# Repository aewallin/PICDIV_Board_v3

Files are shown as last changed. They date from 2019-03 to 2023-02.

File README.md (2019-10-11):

# PICDIV_Board_v3
Programmable 10 MHz to 1PPS frequency divider-board.

The input frequency (sine or square-wave) is first converted to a square-wave and then used as the clock source for a PIC12F675 programmed with the PICDIV firmware (https://github.com/aewallin/PICDIV). Two IDT 5PB1108 buffered outputs are provided. Trimmer-capacitors can be used to accurately tune channel-skew. An LED driven by a timer LTC6993 provides indication of 1PPS signal. A Sync input allows synchronizing the output-1PPS to an input-1PPS, within 100ns (with a 10 MHz clock).

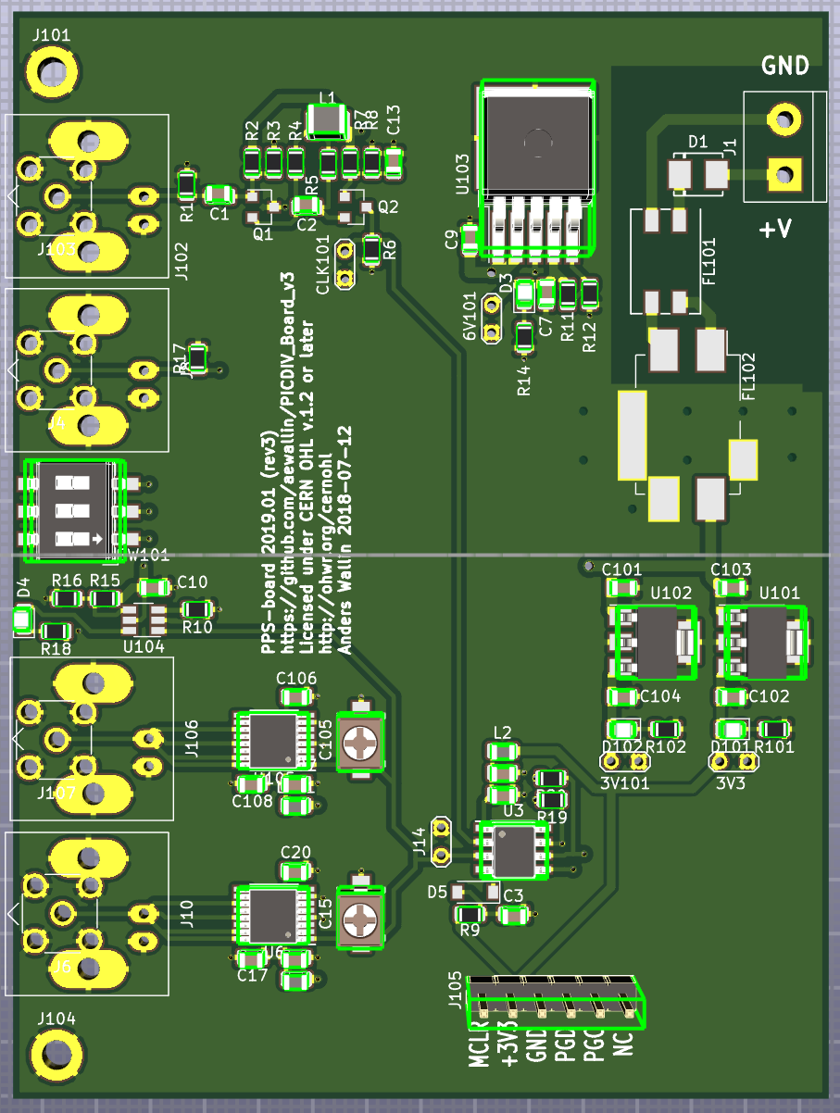
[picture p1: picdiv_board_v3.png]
PCB image


## Firmware

- assembler & build-instructions: https://github.com/aewallin/PICDIV
- original source: http://www.leapsecond.com/pic/picdiv.htm

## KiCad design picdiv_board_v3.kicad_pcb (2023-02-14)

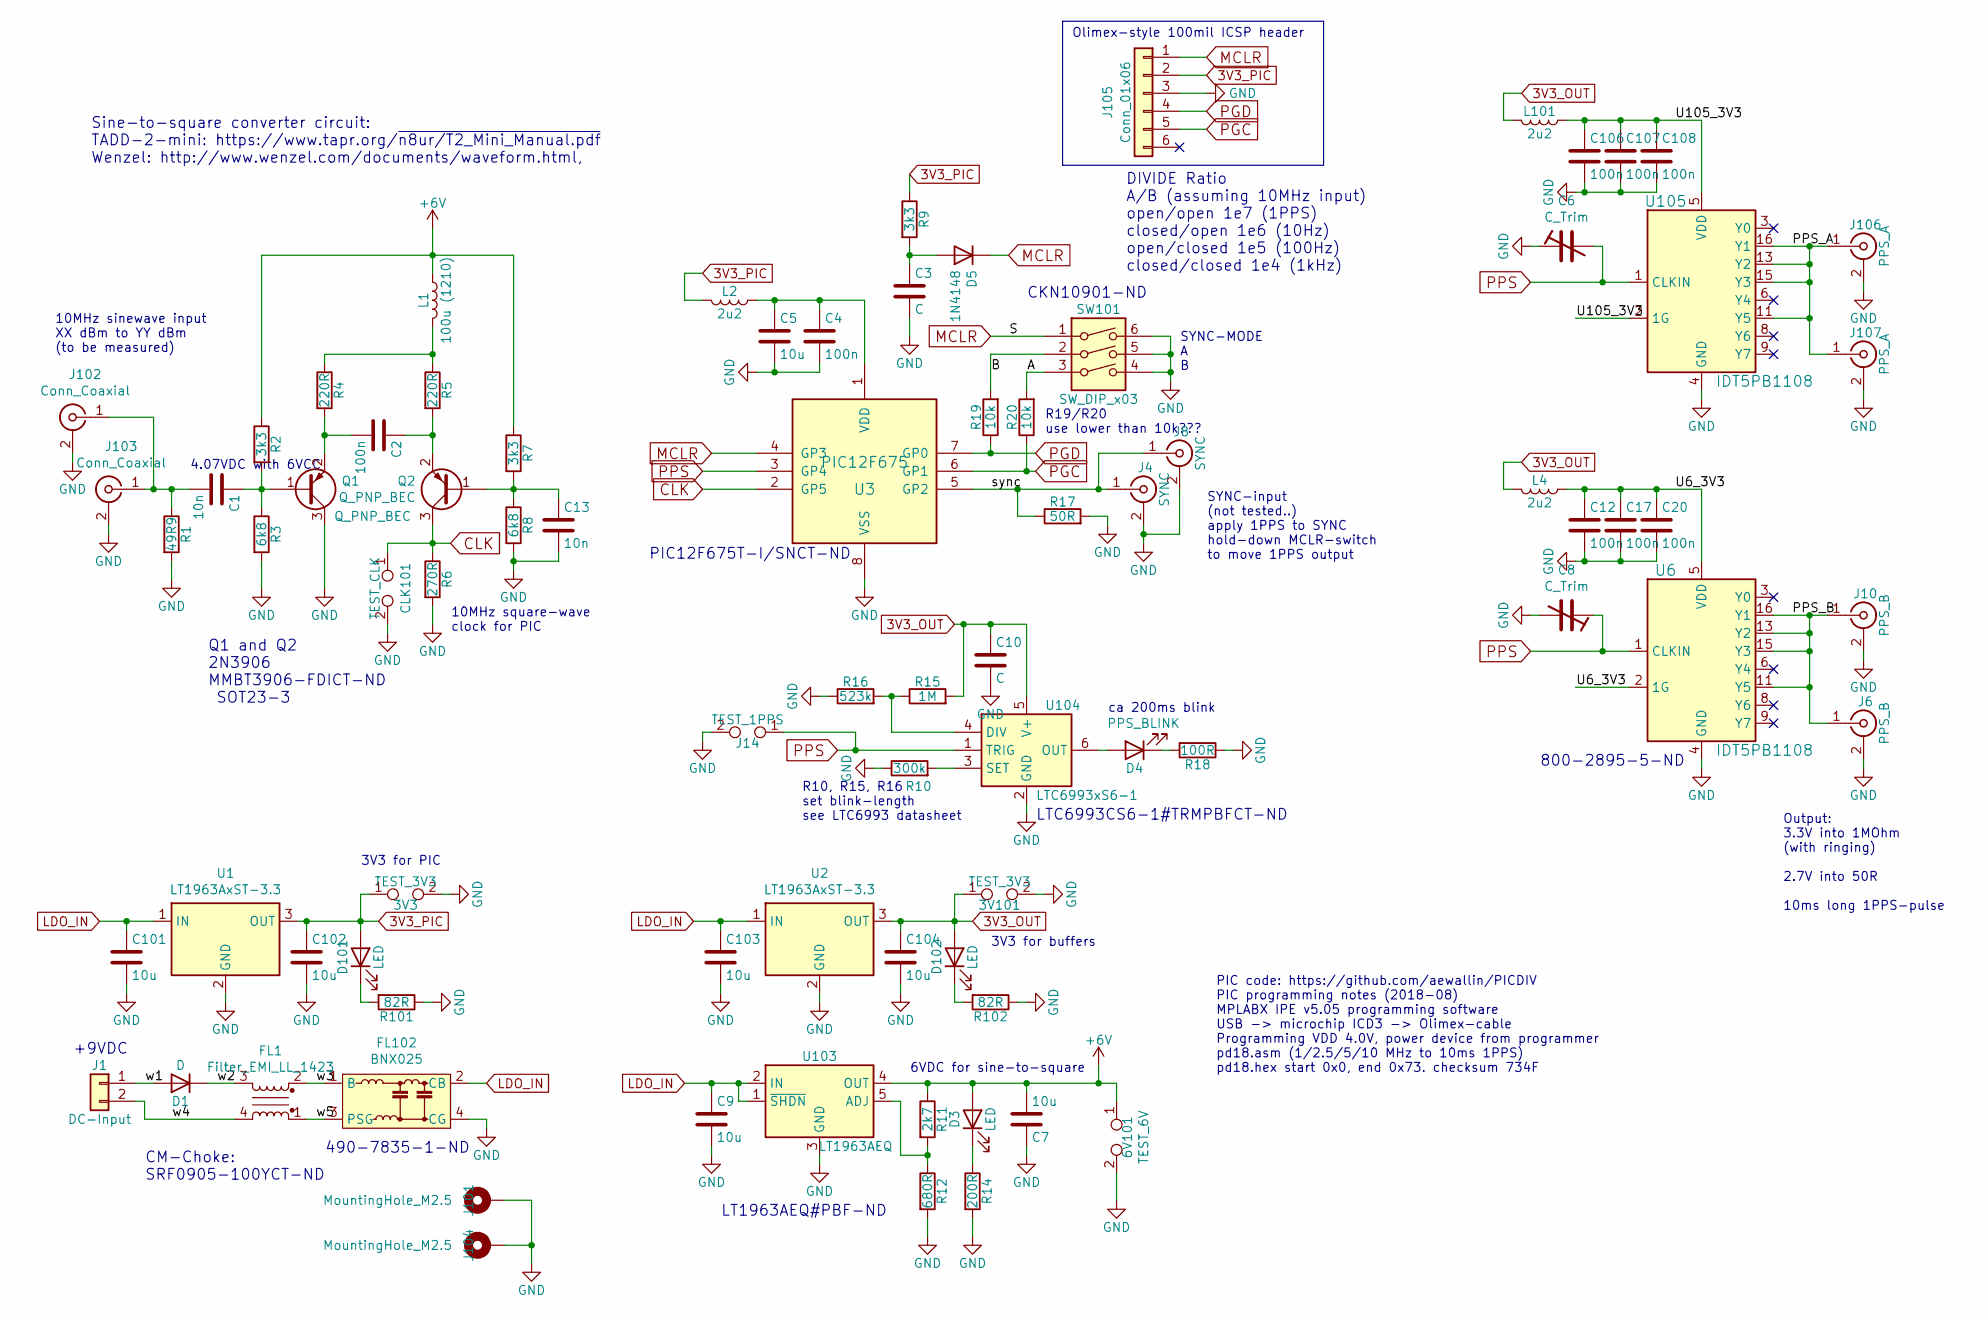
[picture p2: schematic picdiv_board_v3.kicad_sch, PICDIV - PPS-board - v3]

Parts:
3V3, 3V101: TEST_3V3; TestPoint_2Pads_Pitch2.54mm_Drill0.8mm
6V101: TEST_6V; TestPoint_2Pads_Pitch2.54mm_Drill0.8mm
C1, C13: 10n; C_0805_2012Metric
C2, C4, C12, C17, C20, C106, C107, C108: 100n; C_0805_2012Metric
C3, C10: C; C_0805_2012Metric
C5, C7, C9, C101, C102, C103, C104: 10u; C_0805_2012Metric
C6, C8: C_Trim; C_Trimmer_Murata_TZB4-A
CLK101: TEST_CLK; TestPoint_2Pads_Pitch2.54mm_Drill0.8mm
D1: D; DIODE_DO-214BA
D3, D101, D102: LED; LED_0805_2012Metric
D4: PPS_BLINK; LED_0805_2012Metric
D5: 1N4148; D_SOD-123
FL1: Filter_EMI_LL_1423; Filter_Bourns_SRF0905_6.0x9.2mm
FL102: BNX025; Filter_Murata_BNX025_ThermalVias
J1: DC-Input; TerminalBlock_bornier-2_P5.08mm
J4: SYNC; SMA_Molex_73251-2200_Horizontal
J6: PPS_B; SMA_Molex_73251-2200_Horizontal
J8: SYNC; BNC_Amphenol_B6252HB-NPP3G-50_Horizontal
J10: PPS_B; BNC_Amphenol_B6252HB-NPP3G-50_Horizontal
J14: TEST_1PPS; TestPoint_2Pads_Pitch2.54mm_Drill0.8mm
J101, J104: MountingHole_M2.5; MountingHole_2.7mm_M2.5_DIN965_Pad
J102: Conn_Coaxial; BNC_Amphenol_B6252HB-NPP3G-50_Horizontal
J103: Conn_Coaxial; SMA_Molex_73251-2200_Horizontal
J105: Conn_01x06; PinHeader_1x06_P2.54mm_Vertical
J106: PPS_A; BNC_Amphenol_B6252HB-NPP3G-50_Horizontal
J107: PPS_A; SMA_Molex_73251-2200_Horizontal
L1: 100u (1210); L_1210_3225Metric
L2, L4, L101: 2u2; L_0805_2012Metric
Q1, Q2: Q_PNP_BEC; SOT-23
R1: 49R9; R_0805_2012Metric
R2, R7, R9: 3k3; R_0805_2012Metric
R3, R8: 6k8; R_0805_2012Metric
R4, R5: 220R; R_0805_2012Metric
R6: 270R; R_0805_2012Metric
R10: 300k; R_0805_2012Metric
R11: 2k7; R_0805_2012Metric
R12: 680R; R_0805_2012Metric
R14: 200R; R_0805_2012Metric
R15: 1M; R_0805_2012Metric
R16: 523k; R_0805_2012Metric
R17: 50R; R_0805_2012Metric
R18: 100R; R_0805_2012Metric
R19, R20: 10k; R_0805_2012Metric
R101, R102: 82R; R_0805_2012Metric
SW101: SW_DIP_x03; SW_DIP_SPSTx03_Slide_6.7x9.18mm_W8.61mm_P2.54mm_LowProfile
U1, U2: LT1963AxST-3.3; SOT-223-3_TabPin2
U3: PIC12F675; SOIC-8_3.9x4.9mm_P1.27mm
U6, U105: IDT5PB1108; TSSOP-16_4.4x5mm_P0.65mm
U103: LT1963AEQ; TO-263-5_TabPin3
U104: LTC6993xS6-1; TSOT-23-6

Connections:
3V3_OUT: 3V101.1, C10.1, C104.1, D102.2 (A), L4.2, L101.2, R15.2, U2.3 (OUT), U104.5 (V+)
3V3_PIC: 3V3.1, C102.1, D101.2 (A), J105.2, L2.2, R9.1, U1.3 (OUT)
+6V: 6V101.1, C7.2, D3.2 (A), L1.1, R2.1, R7.1, R11.1, U103.4 (OUT)
/A: R20.2, SW101.3
/B: R19.2, SW101.2
/PPS_A: J106.1 (In), J107.1 (In), U105.11 (Y5), U105.13 (Y2), U105.15 (Y3), U105.16 (Y1)
/PPS_B: J6.1 (In), J10.1 (In), U6.11 (Y5), U6.13 (Y2), U6.15 (Y3), U6.16 (Y1)
/U6_3V3: C12.1, C17.1, C20.1, L4.1, U6.2 (1G), U6.5 (VDD), U6.10 (VDD), U6.14 (VDD)
/U105_3V3: C106.1, C107.1, C108.1, L101.1, U105.2 (1G), U105.5 (VDD), U105.10 (VDD), U105.14 (VDD)
/sync: J4.1 (In), J8.1 (In), R17.1, U3.5 (GP2)
/w1: D1.2 (A), J1.1
/w2: D1.1 (K), FL1.3
/w3: FL1.2, FL102.1 (B)
/w4: FL1.4, J1.2
/w5: FL1.1, FL102.3 (PSG)
CLK: CLK101.1, Q2.3 (C), R6.1, U3.2 (GP5)
GND: 3V3.2, 3V101.2, 6V101.2, C3.2, C4.2, C5.2, C6.1, C7.1, C8.2, C9.2, C10.2, C12.2, C13.2, C17.2, C20.2, C101.2, C102.2, C103.2, C104.2, C106.2, C107.2, C108.2, CLK101.2, FL102.4 (CG), J4.2 (Ext), J6.2 (Ext), J8.2 (Ext), J10.2 (Ext), J14.2, J101.1, J102.2 (Ext), J103.2 (Ext), J104.1, J105.3, J106.2 (Ext), J107.2 (Ext), Q1.3 (C), R1.2, R3.2, R6.2, R8.2, R10.1, R12.2, R14.2, R16.1, R17.2, R18.1, R101.1, R102.1, SW101.4, SW101.5, SW101.6, U1.2 (GND), U2.2 (GND), U3.8 (VSS), U6.4 (GND), U6.7 (GND), U6.12 (GND), U103.3 (GND), U104.2 (GND), U105.4 (GND), U105.7 (GND), U105.12 (GND)
LDO_IN: C9.1, C101.1, C103.1, FL102.2 (CB), U1.1 (IN), U2.1 (IN), U103.1 (~SHDN), U103.2 (IN)
MCLR: D5.1 (K), J105.1, SW101.1, U3.4 (GP3)
unnamed: C1.1, Q1.1 (B), R2.2, R3.1
unnamed: C1.2, J102.1 (In), J103.1 (In), R1.1
unnamed: C2.1, Q2.2 (E), R5.2
unnamed: C2.2, Q1.2 (E), R4.2
unnamed: C3.1, D5.2 (A), R9.2
unnamed: C4.1, C5.1, L2.1, U3.1 (VDD)
unnamed: C13.1, Q2.1 (B), R7.2, R8.1
unnamed: D3.1 (K), R14.1
unnamed: D4.1 (K), R18.2
unnamed: D4.2 (A), U104.6 (OUT)
unnamed: D101.1 (K), R101.2
unnamed: D102.1 (K), R102.2
unnamed: L1.2, R4.1, R5.1
unnamed: R10.2, U104.3 (SET)
unnamed: R11.2, R12.1, U103.5 (ADJ)
unnamed: R15.1, R16.2, U104.4 (DIV)
PGC: J105.5, R20.1, U3.6 (GP1)
PGD: J105.4, R19.1, U3.7 (GP0)
PPS: C6.2, C8.1, J14.1, U3.3 (GP4), U6.1 (CLKIN), U104.1 (TRIG), U105.1 (CLKIN)

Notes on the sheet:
LT1963AEQ#PBF-ND
PIC code: https://github.com/aewallin/PICDIV PIC programming notes (2018-08) MPLABX IPE v5.05 programming software USB -> microchip ICD3 -> Olimex-cable Programming VDD 4.0V, power device from programmer pd18.asm (1/2.5/5/10 MHz to 10ms 1PPS) pd18.hex start 0x0, end 0x73. checksum 734F
+9VDC
10MHz square-wave clock for PIC
DIVIDE Ratio A/B (assuming 10MHz input) open/open 1e7 (1PPS) closed/open 1e6 (10Hz) open/closed 1e5 (100Hz) closed/closed 1e4 (1kHz)
Output: 3.3V into 1MOhm (with ringing) 2.7V into 50R 10ms long 1PPS-pulse
ca 200ms blink
SYNC-MODE A B
R10, R15, R16 set blink-length see LTC6993 datasheet
LTC6993CS6-1#TRMPBFCT-ND
CKN10901-ND
3V3 for buffers
Sine-to-square converter circuit: TADD-2-mini: https://www.tapr.org/~{n8ur/T2_Mini_Manual.pdf} Wenzel: http://www.wenzel.com/documents/waveform.html,
CM-Choke: SRF0905-100YCT-ND
490-7835-1-ND
Olimex-style 100mil ICSP header
R19/R20 use lower than 10k???
Q1 and Q2 2N3906 MMBT3906-FDICT-ND SOT23-3
800-2895-5-ND
6VDC for sine-to-square
3V3 for PIC
10MHz sinewave input XX dBm to YY dBm (to be measured)
PIC12F675T-I/SNCT-ND
SYNC-input (not tested..) apply 1PPS to SYNC hold-down MCLR-switch to move 1PPS output
4.07VDC with 6VCC

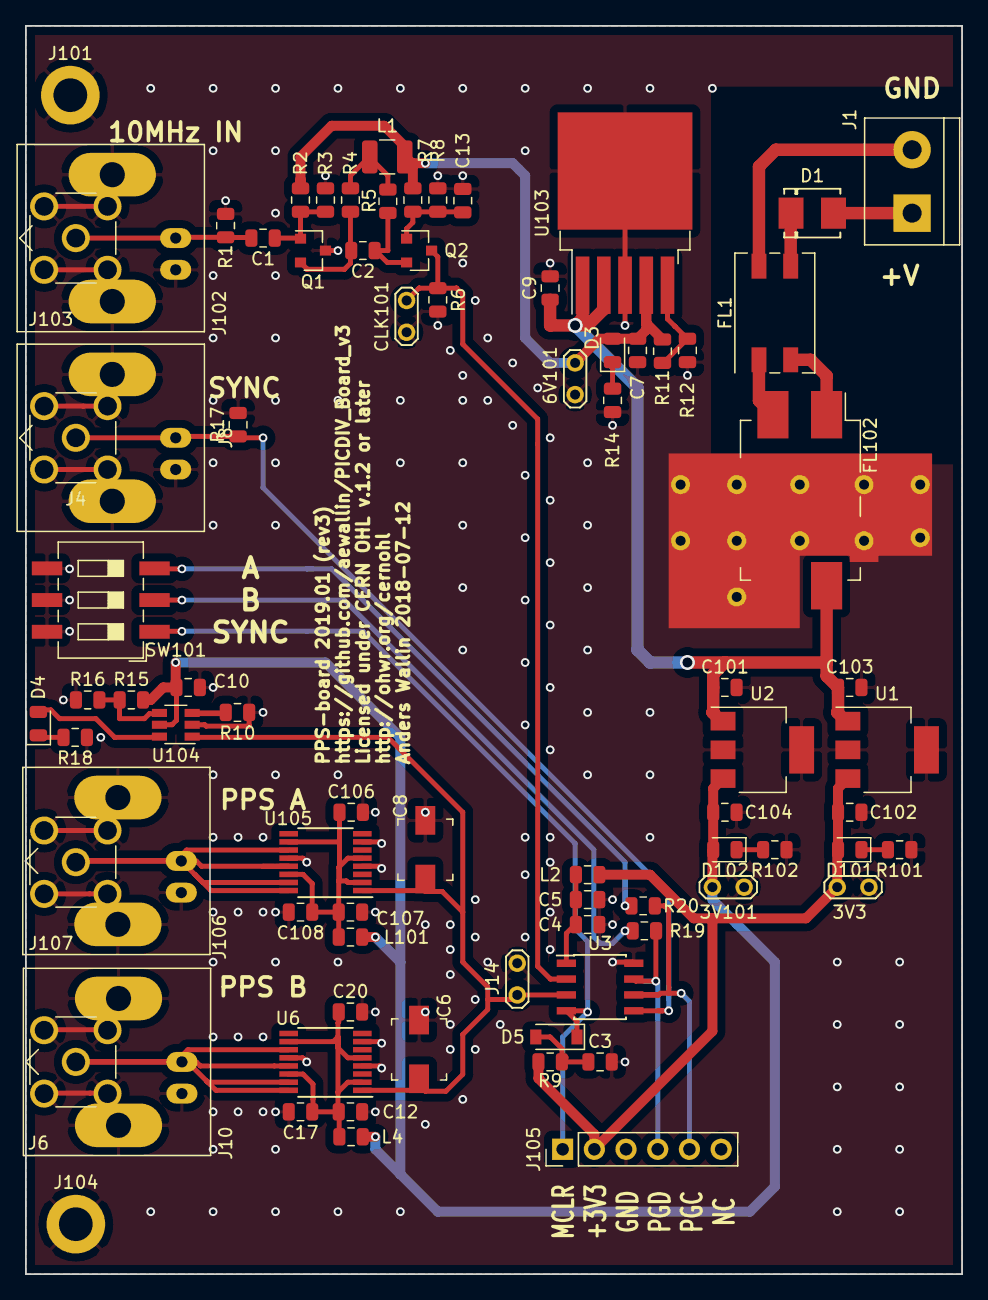
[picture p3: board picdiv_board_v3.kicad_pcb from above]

Board: 2 copper layers, 75.0 x 100.0 mm, 81 parts (0 on the bottom side), 38 nets.

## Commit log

2019-01-19 initial commit of old files - draft and broken!
    [picdiv_board_v3.kicad_pcb, picdiv_board_v3.sch]
2019-01-19 initial layout, symbols to kicad5
    [picdiv_board_v3.kicad_pcb, picdiv_board_v3.sch]
2019-01-22 pcb passes DRC
    [picdiv_board_v3.kicad_pcb, picdiv_board_v3.sch]
2019-03-16 add descriptions of DC
    [picdiv_board_v3.sch]
2019-03-16 add URL to silk
    [picdiv_board_v3.kicad_pcb]
2019-03-16 add 3D view screenshot of PCB
2019-03-16 gnd-vias, silk, move PPSB connectors.
    [picdiv_board_v3.kicad_pcb, picdiv_board_v3.sch]
2021-01-23 minor updates
    [picdiv_board_v3.kicad_pcb, picdiv_board_v3.sch]
2021-09-23 fix missing symbols (kicad lib)
    [picdiv_board_v3.kicad_pcb, picdiv_board_v3.sch]
2022-12-09 kicad6 version
    [picdiv_board_v3.kicad_pcb, picdiv_board_v3.kicad_sch]
2022-12-09 remove old kicad5 version
    [picdiv_board_v3.sch]

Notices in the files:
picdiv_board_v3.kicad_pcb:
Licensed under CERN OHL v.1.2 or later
